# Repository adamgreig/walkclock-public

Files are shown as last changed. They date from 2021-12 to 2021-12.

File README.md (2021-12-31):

# walkclock

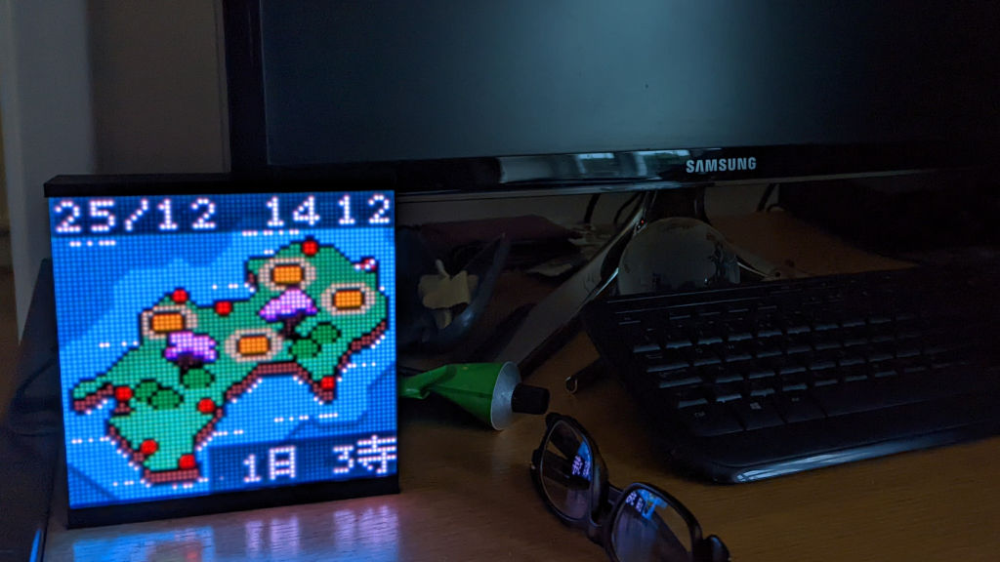
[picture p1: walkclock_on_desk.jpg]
walkclock on a desk


A clock that shows a map with a route that progresses day-by-day.

Display is a 64x64px LED matrix, driven by an STM32H743 on a WeAct dev board.

## Simulator

To run the simulator on a desktop:

```
cd simulator/
cargo run --release
```

The following keyboard buttons are mapped to the buttons on the hardware:

* Q/Backspace/Up: BACK
* W: QR
* E: DISPLAY
* A/Enter/Down: ENTER
* S/Left: LEFT
* D/Right: RIGHT

## Firmware

To program the firmware:

```
cd firmware/
cargo embed --release
```

Use `cargo embed --release rtt` to also attach an RTT session.

## Other Assets

* `mechanical/` contains design files for the 3d-printed holder and laser-cut
  acrylic diffuser
* `artwork/` contains the various maps and images, and a script to extract
  route pixel data from XCF files

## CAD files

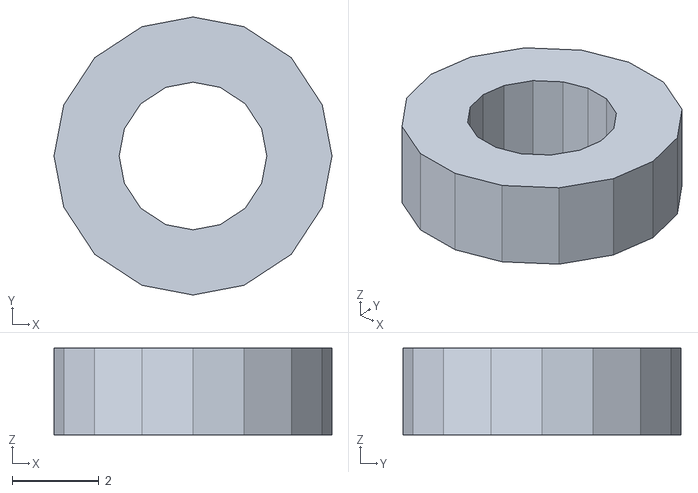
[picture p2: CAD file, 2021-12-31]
mechanical/m3_spacer.stl
6.40 x 6.40 x 2.00

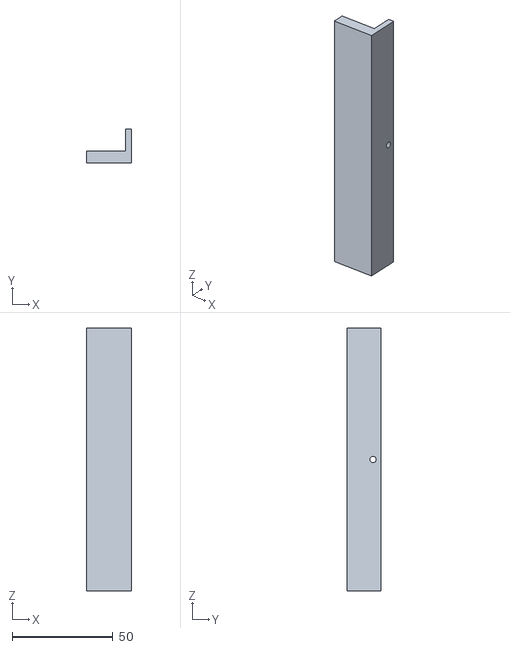
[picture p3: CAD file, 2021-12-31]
mechanical/top_v2.stl
22.2 x 17.0 x 130.5

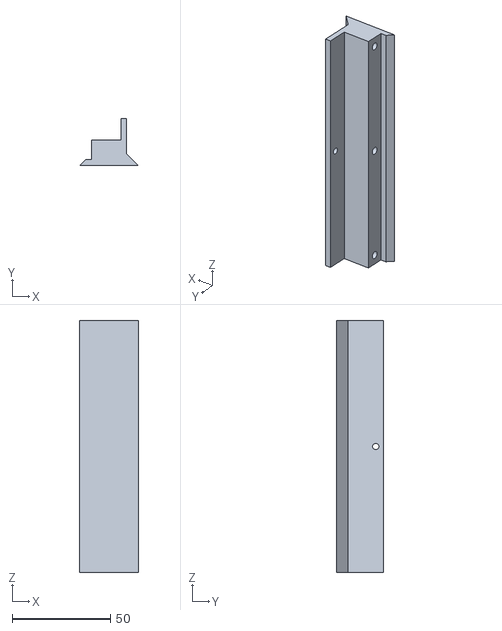
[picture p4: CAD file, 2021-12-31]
mechanical/base.stl
30.0 x 24.0 x 128.0

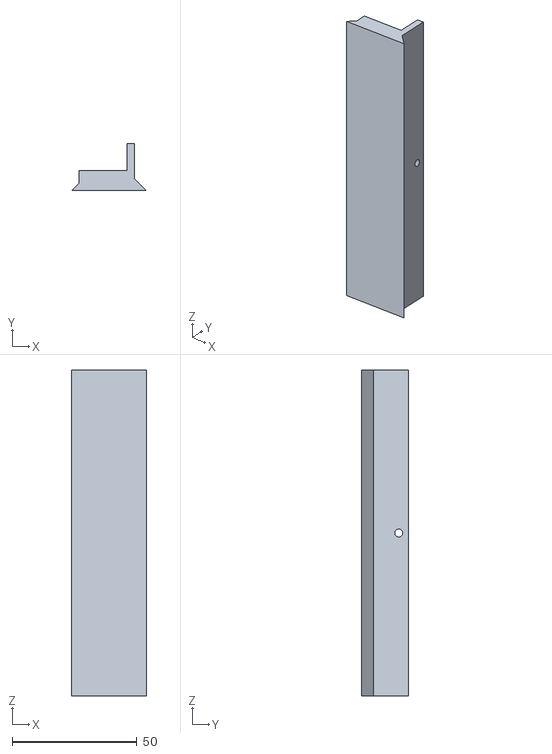
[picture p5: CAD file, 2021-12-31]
mechanical/base_v2.stl
30.0 x 19.0 x 130.5

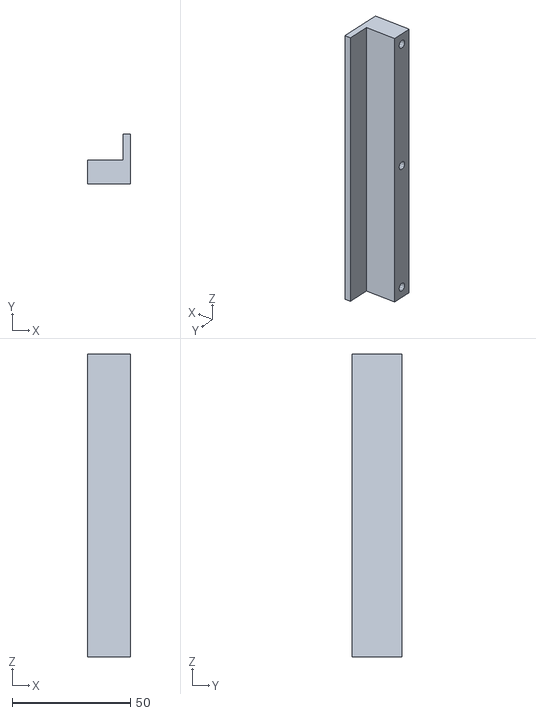
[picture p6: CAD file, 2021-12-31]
mechanical/top.stl
18.0 x 21.0 x 128.0

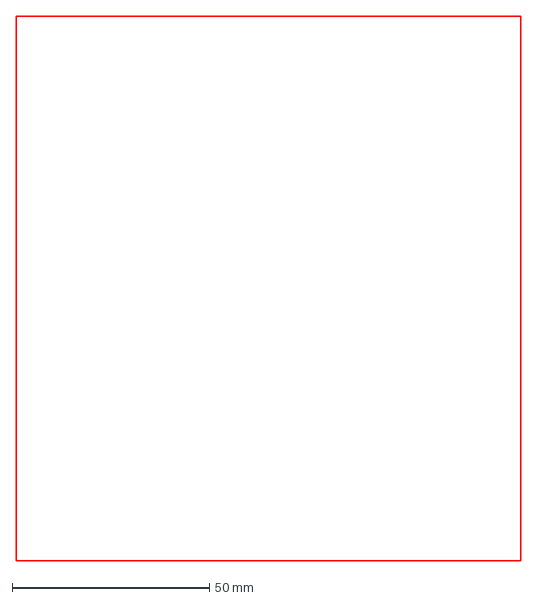
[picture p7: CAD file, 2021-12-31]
mechanical/diffuser_v2.dxf
128.0 x 138.0 mm

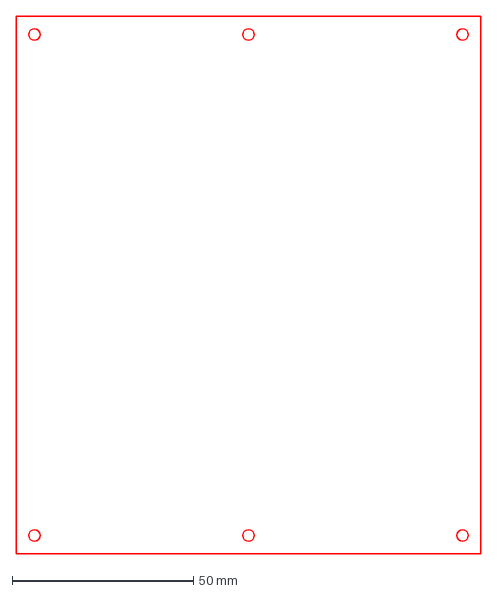
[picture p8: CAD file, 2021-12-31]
mechanical/diffuser.dxf
128.0 x 148.0 mm

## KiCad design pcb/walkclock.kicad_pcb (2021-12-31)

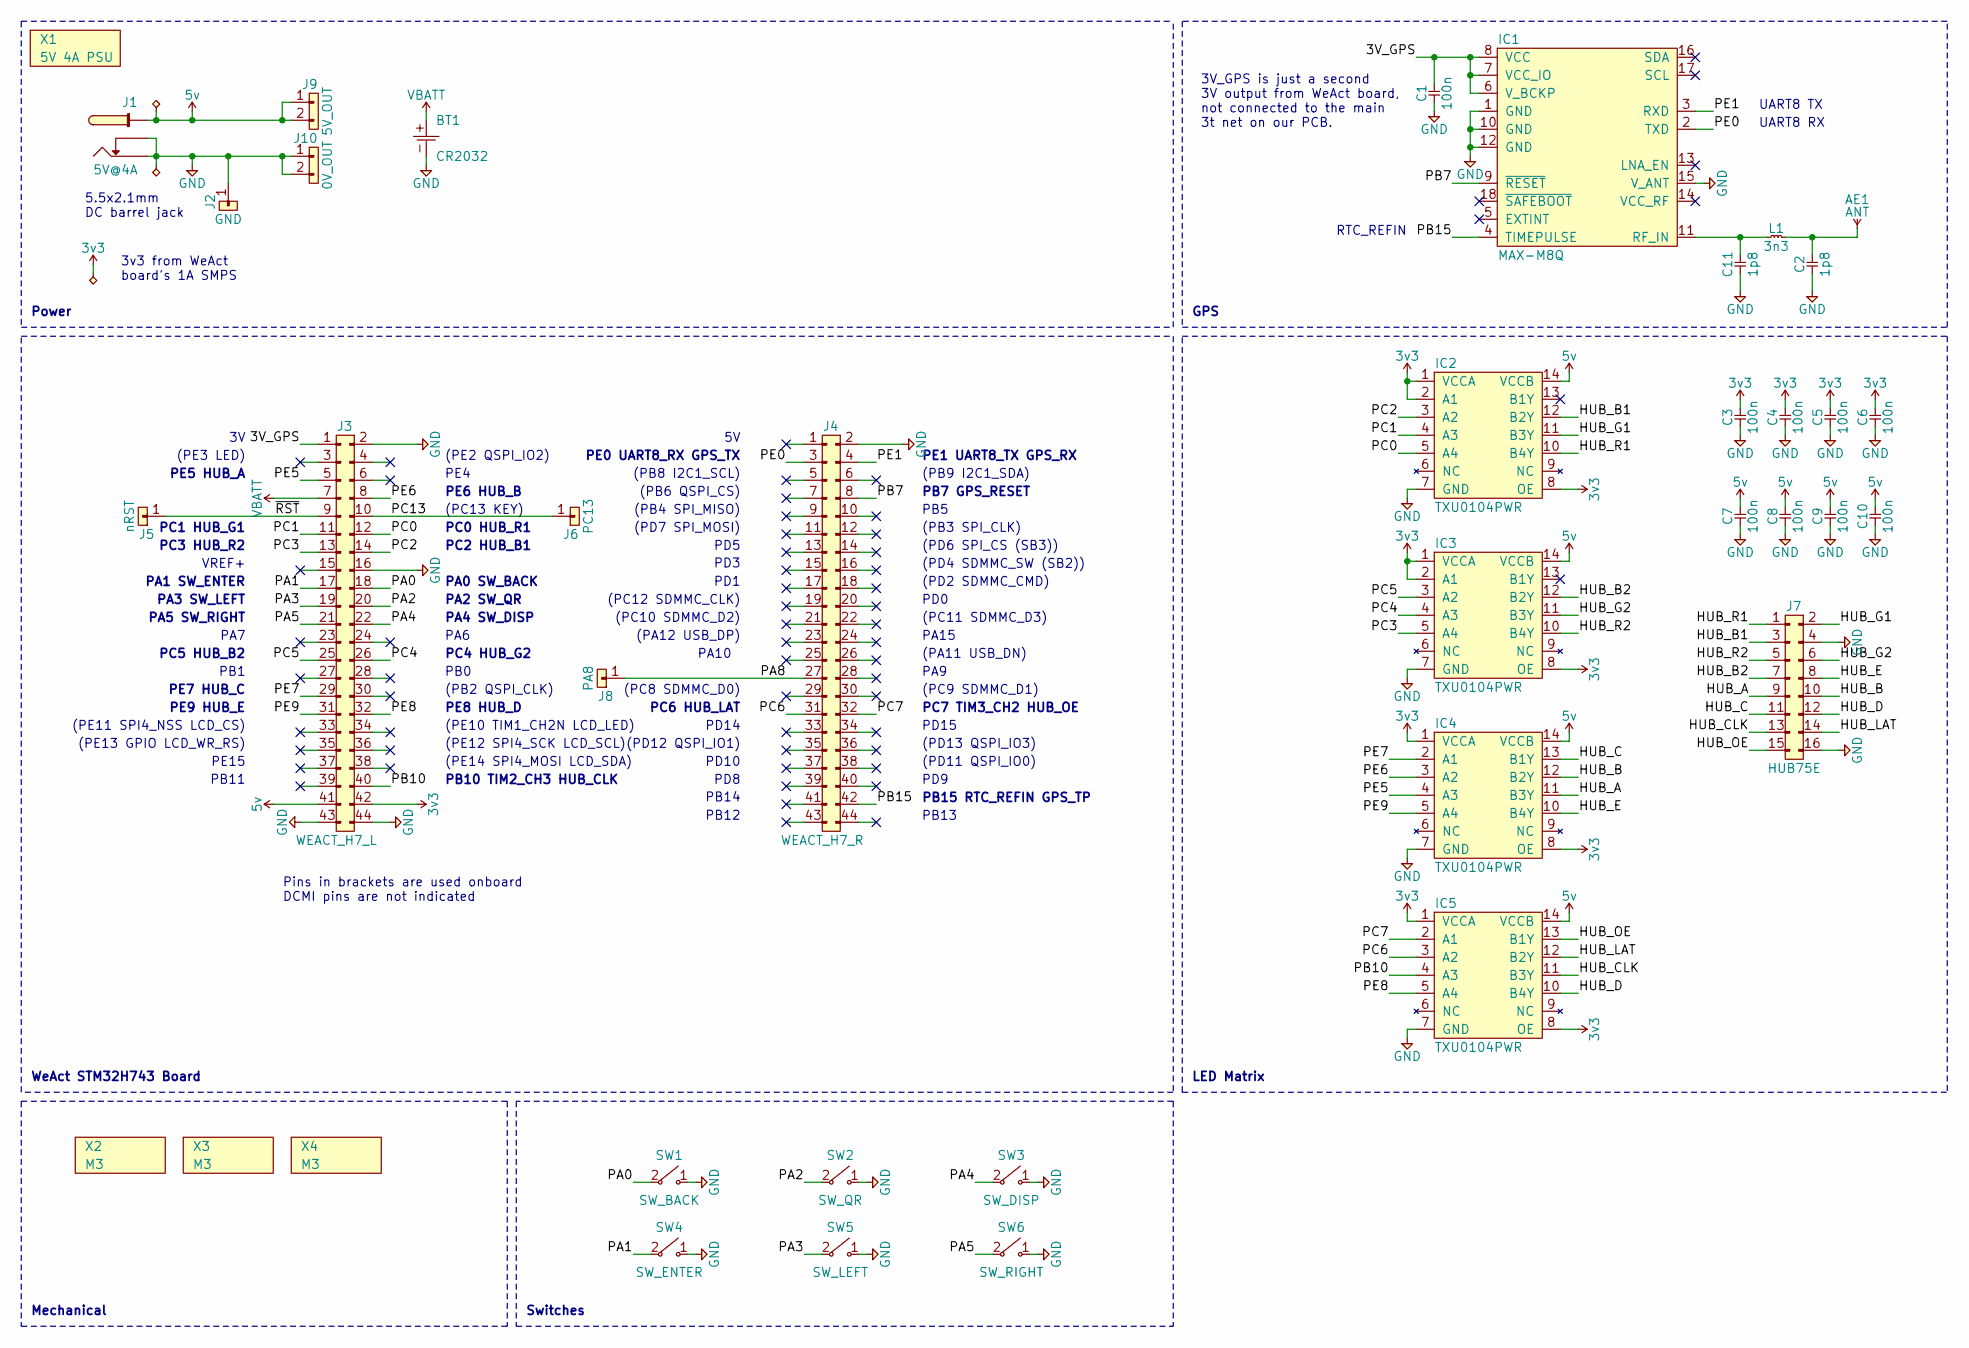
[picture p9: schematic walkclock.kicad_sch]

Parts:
AE1: ANT; NN01-103; Mouser 128-NN01-103
BT1: CR2032; KEYSTONE_103
C1, C3, C4, C5, C6, C7, C8, C9, C10: 100n; 0402; Mouser 963-TMK105BJ104KV8F
C2, C11: 1p8; 0402; Mouser 80-CBR04C189A5GAC
IC1: MAX-M8Q
IC2, IC3, IC4, IC5: TXU0104PWR; TSSOP-14; Mouser 595-TXU0104PWR
J1: 5V@4A; BARRELJACK
J2: GND; SIL-254P-01
J3: WEACT_H7_L; DIL-254P-44; Mouser 200-SSW12201FD
J4: WEACT_H7_R; DIL-254P-44; Mouser 200-SSW12201FD
J5: nRST; SIL-254P-01
J6: PC13; SIL-254P-01
J7: HUB75E; DIL-254P-16; Mouser 200-SSW10801FD
J8: PA8; SIL-254P-01
J9: 5V_OUT; SIL-254P-02
J10: 0V_OUT; SIL-254P-02
L1: 3n3; 0402; Mouser 81-LQW15AN3N3D10D
SW1: SW_BACK; SW_MOM_6X6; Mouser 179-TS046670BK260SMT
SW2: SW_QR; SW_MOM_6X6; Mouser 179-TS046670BK260SMT
SW3: SW_DISP; SW_MOM_6X6; Mouser 179-TS046670BK260SMT
SW4: SW_ENTER; SW_MOM_6X6; Mouser 179-TS046670BK260SMT
SW5: SW_LEFT; SW_MOM_6X6; Mouser 179-TS046670BK260SMT
SW6: SW_RIGHT; SW_MOM_6X6; Mouser 179-TS046670BK260SMT
X1: 5V 4A PSU; Mouser 418-TRE25050U11G02VI
X2, X3, X4: M3; M3_HOLE

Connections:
3v3: C3.2, C4.2, C5.2, C6.2, IC2.1 (VCCA), IC2.2 (A1), IC2.8 (OE), IC3.1 (VCCA), IC3.2 (A1), IC3.8 (OE), IC4.1 (VCCA), IC4.8 (OE), IC5.1 (VCCA), IC5.8 (OE), J3.42
5v: C7.2, C8.2, C9.2, C10.2, IC2.14 (VCCB), IC3.14 (VCCB), IC4.14 (VCCB), IC5.14 (VCCB), J1.1 (TIP), J3.41, J9.1, J9.2
/3V_GPS: C1.2, IC1.6 (V_BCKP), IC1.7 (VCC_IO), IC1.8 (VCC), J3.1
/HUB_A: IC4.11 (B3Y), J7.9
/HUB_B: IC4.12 (B2Y), J7.10
/HUB_B1: IC2.12 (B2Y), J7.3
/HUB_B2: IC3.12 (B2Y), J7.7
/HUB_C: IC4.13 (B1Y), J7.11
/HUB_CLK: IC5.11 (B3Y), J7.13
/HUB_D: IC5.10 (B4Y), J7.12
/HUB_E: IC4.10 (B4Y), J7.8
/HUB_G1: IC2.11 (B3Y), J7.2
/HUB_G2: IC3.11 (B3Y), J7.6
/HUB_LAT: IC5.12 (B2Y), J7.14
/HUB_OE: IC5.13 (B1Y), J7.15
/HUB_R1: IC2.10 (B4Y), J7.1
/HUB_R2: IC3.10 (B4Y), J7.5
/PA0: J3.18, SW1.2 ("~")
/PA1: J3.17, SW4.2 ("~")
/PA2: J3.20, SW2.2 ("~")
/PA3: J3.19, SW5.2 ("~")
/PA4: J3.22, SW3.2 ("~")
/PA5: J3.21, SW6.2 ("~")
/PA8: J4.27, J8.1
/PB7: IC1.9 (~RESET), J4.8
/PB10: IC5.4 (A3), J3.40
/PB15: IC1.4 (TIMEPULSE), J4.42
/PC0: IC2.5 (A4), J3.12
/PC1: IC2.4 (A3), J3.11
/PC2: IC2.3 (A2), J3.14
/PC3: IC3.5 (A4), J3.13
/PC4: IC3.4 (A3), J3.26
/PC5: IC3.3 (A2), J3.25
/PC6: IC5.3 (A2), J4.31
/PC7: IC5.2 (A1), J4.32
/PC13: J3.10, J6.1
/PE0: IC1.2 (TXD), J4.3
/PE1: IC1.3 (RXD), J4.4
/PE5: IC4.4 (A3), J3.5
/PE6: IC4.3 (A2), J3.8
/PE7: IC4.2 (A1), J3.29
/PE8: IC5.5 (A4), J3.32
/PE9: IC4.5 (A4), J3.31
/~RST: J3.9, J5.1
GND: BT1.-, C1.1, C2.1, C3.1, C4.1, C5.1, C6.1, C7.1, C8.1, C9.1, C10.1, C11.1, IC1.1 (GND), IC1.10 (GND), IC1.12 (GND), IC1.15 (V_ANT), IC2.7 (GND), IC3.7 (GND), IC4.7 (GND), IC5.7 (GND), J1.2 (SW), J1.3 (RING), J2.1, J3.2, J3.16, J3.43, J3.44, J4.2, J7.4, J7.16, J10.1, J10.2, SW1.1 ("~"), SW2.1 ("~"), SW3.1 ("~"), SW4.1 ("~"), SW5.1 ("~"), SW6.1 ("~")
unnamed: AE1.1, C2.2, L1.2
unnamed: C11.2, IC1.11 (RF_IN), L1.1
VBATT: BT1.+, J3.7

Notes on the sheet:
(PE11 SPI4_NSS LCD_CS)
(PA11 USB_DN)
PD14
PC1 HUB_G1
5.5x2.1mm DC barrel jack
PD15
Mechanical
PC2 HUB_B1
GPS
(PE13 GPIO LCD_WR_RS)
PE8 HUB_D
UART8 RX
(PB2 QSPI_CLK)
PA7
(PC8 SDMMC_D0)
PA3 SW_LEFT
(PC12 SDMMC_CLK)
(PE10 TIM1_CH2N LCD_LED)
Switches
(PC9 SDMMC_D1)
(PC11 SDMMC_D3)
(PD12 QSPI_IO1)
PC3 HUB_R2
PD9
(PD6 SPI_CS (SB3))
UART8 TX
(PD4 SDMMC_SW (SB2))
(PB6 QSPI_CS)
3v3 from WeAct board's 1A SMPS
(PE12 SPI4_SCK LCD_SCL)
PE0 UART8_RX GPS_TX
PD8
PA15
PB1
(PE2 QSPI_IO2)
PE1 UART8_TX GPS_RX
PE5 HUB_A
PE6 HUB_B
PC4 HUB_G2
PB14

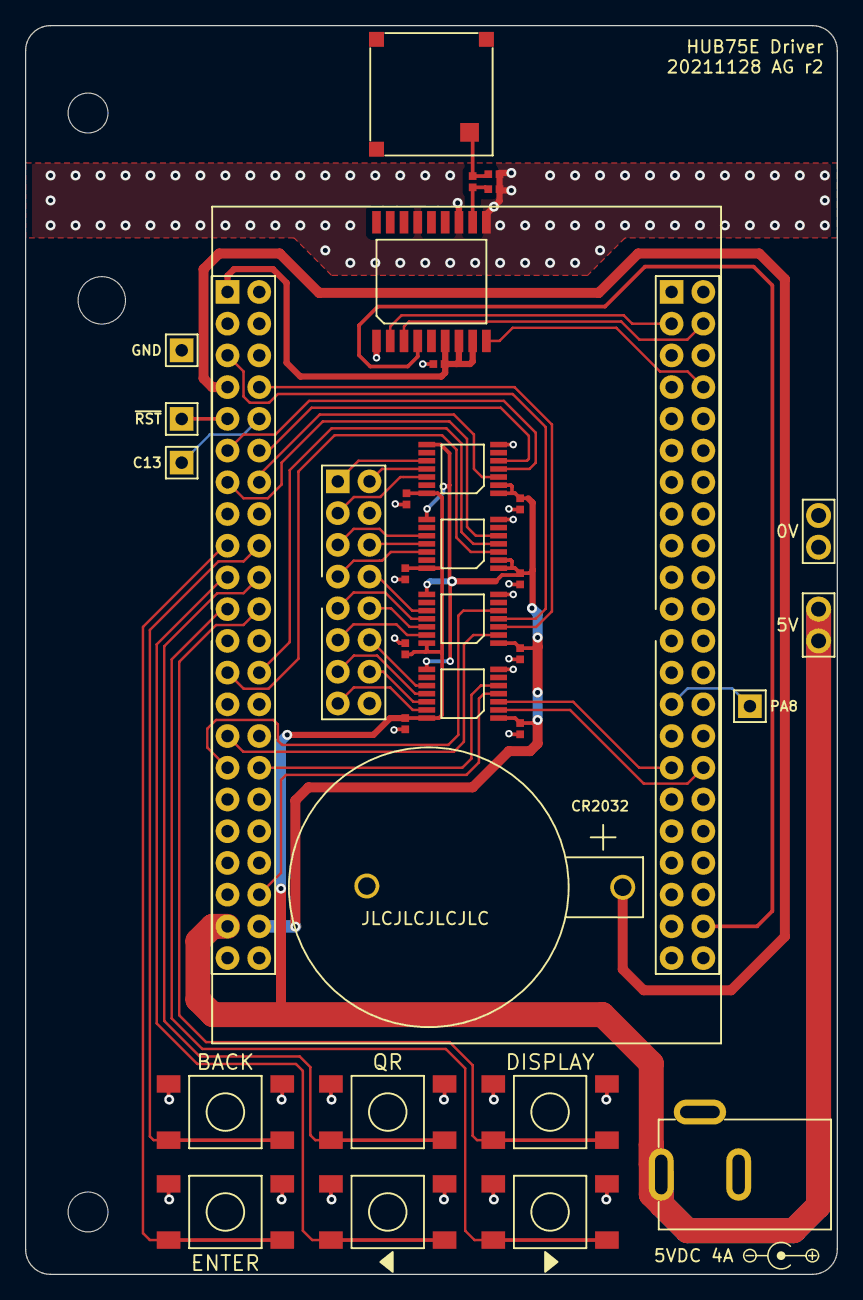
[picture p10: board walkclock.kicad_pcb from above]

Board: 2 copper layers, 65.0 x 100.0 mm, 38 parts (0 on the bottom side), 48 nets.

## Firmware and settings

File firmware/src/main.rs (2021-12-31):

#![no_std]
#![no_main]

use panic_rtt_target as _;
mod dma;
mod dma2d;
mod framebuf;
mod gpio;
mod hub75e;
mod lcd;
mod rcc;
mod rtc;
mod spi;
mod switches;
mod tim;
mod uart;
mod ublox;

mod jpeg;

pub type LineBuf = [u8; 65];

#[rtic::app(device=stm32ral::stm32h7::stm32h743v, dispatchers=[WKUP])]
mod app {
    use crate::{
        dma, dma2d, gpio, jpeg, rcc, rtc, spi, tim, uart,
        lcd::Lcd, ublox::{UBlox, PVTError}, switches::Switches, hub75e::Hub75E,
        LineBuf, framebuf::{FrameBuf, MainFrameBuf, SubFrameBuf},
    };
    use rtt_target::{rtt_init_print, rprintln, rprint};
    use walkclock::Clock;

    /// Double-buffered RGB888 frame buffers for main HUB75E display.
    static mut MFBUFS: [MainFrameBuf; 2] = [FrameBuf([[[0u8; 3]; 64]; 64]); 2];

    /// Output buffers for HUB75E driver, which is read by DMA1 so goes in SRAM1.
    ///
    /// NOTE: Despite being set to 0, SRAM1 is not initialised by the runtime,
    /// so this buffer starts life uninitialised. However, we only ever write
    /// to it from Rust and it's only read by DMA, so we sort of avoid UB.
    #[link_section=".sram1.lbufs"]
    static mut LBUFS: [LineBuf; 2] = [[0u8; 65]; 2];

    /// Single-buffered RGB888 frame buffer for LCD display.
    ///
    /// NOTE: Stored in SRAM2 to enable direct access by DMA,
    ///       while not contending with SRAM1 for the main display.
    #[link_section=".sram2.sfbuf"]
    static mut SFBUF: SubFrameBuf = FrameBuf([[[0u8; 3]; 160]; 80]);

    /// Reception buffer for UART.
    /// NOTE: Stored in SRAM2 to enable direct access by DMA.
    #[link_section=".sram2.uartbuf"]
    static mut UARTBUF: [u8; 100] = [0u8; 100];

    /// TIM15 capture buffer.
    /// Captures 2049 LSE edge timestamps to reconstruct 2048 LSE period measurements,
    /// or half a second worth of LSE ticks at 32768Hz LSE with timer input prescaler 8.
    /// NOTE: Stored in SRAM2 to enable direct access by DMA.
    #[link_section=".sram2.tim15buf"]
    static mut TIM15BUF: [u16; 2049] = [0u16; 2049];

    /// JPEG decode buffer.
    /// Stores decoded MCUs from the most recently processed JPEG.
    /// NOTE: Stored in AXISRAM as it's spacious and can be accessed by CPU and DMA2D.
    #[link_section=".axisram.jpegdbuf"]
    static mut JPEGDBUF: [u32; 3072] = [0u32; 3072];

    /// JPEG framebuffer.
    /// Stores converted JPEG RGB888 pixels ready for copying into active framebuffer.
    /// NOTE: Stored in AXISRAM as it's spacious and can be accessed by DMA2D.
    #[link_section=".axisram.jpegfbuf"]
    static mut JPEGFBUF: MainFrameBuf = FrameBuf([[[0u8; 3]; 64]; 64]);

    #[shared]
    struct Shared {
        hub: Hub75E,
        lcd: Lcd,
        ublox: UBlox,
        cal: rtc::Calibrator,
    }

    #[local]
    struct Local {
        rtc: rtc::RTC,
        tick_tim: tim::Tim,
        tim12: tim::Tim,
        tim15_dma: dma::DMAStream,
        jpeg: jpeg::Jpeg,
        dma2d: dma2d::DMA2D,
        clock: Clock,
        switches: Switches,
    }

    #[init]
    fn init(mut cx: init::Context) -> (Shared, Local, init::Monotonics) {
        rtt_init_print!();
        rprintln!("WalkClock initialising...");

        // Set up clocks, including PWR voltage scaling and flash wait states.
        rprint!("  RCC...      ");
        let clocks = rcc::setup(cx.device.RCC, cx.device.PWR, cx.device.FLASH);
        rprintln!("OK");

        rprint!("  ICACHE...   ");
        cx.core.SCB.enable_icache();
        rprintln!("OK");

        /*
        rprintln!("Testing JPEG decoder...");
        crate::jpeg::test(cx.device.JPEG);
        rprintln!("Done, continuing...");
        */
        rprint!("  JPEG...     ");
        let jpeg = jpeg::Jpeg::new(cx.device.JPEG);
        rprintln!("OK");

        rprint!("  GPIO...     ");
        let pins = gpio::setup(cx.device.GPIOA, cx.device.GPIOB, cx.device.GPIOC,
                               cx.device.GPIOD, cx.device.GPIOE);
        rprintln!("OK");

        rprint!("  Switches... ");
        // Repeat after the first second and then four times per second thereafter.
        let switches = Switches::new(pins.switches, 20, 5);
        rprintln!("OK");

        rprint!("  RTC...      ");
        let rtc = rtc::RTC::new(cx.device.RTC);
        rprintln!("OK");

        rprint!("  TIM...      ");
        // TIM1 is used to generate the LCD backlight PWM at 250kHz and 1/3 duty cycle.
        // TIM2 is used to generate the HUB75E pixel clock at 15MHz.
        // TIM3 is used to generate the HUB75E OE pulses.
        // TIM4 is used to generate the 20Hz display update ticks, prescaled to 10kHz.
        // TIM15 is used to measure LSE, sending timestamps to a buffer via DMA.
        // If need be, TIM2 can be upped to 18.75MHz for a little more brightness.
        let tim1 = tim::Tim::from_tim1(cx.device.TIM1);
        tim1.setup_lcd_pwm(clocks.tim_ck / 250_000);
        tim1.set_lcd_duty((clocks.tim_ck / 250_000) / 3);
        let tim2 = tim::Tim::from_tim2(cx.device.TIM2);
        tim2.setup_hub_clk(clocks.tim_ck / 15_000_000);
        let tim3 = tim::Tim::from_tim3(cx.device.TIM3);
        tim3.setup_hub_oe();
        let tim4 = tim::Tim::from_tim4(cx.device.TIM4);
        tim4.setup_tick(clocks.tim_ck / 10_000, 500);
        let tim12 = tim::Tim::from_tim12(cx.device.TIM12);
        tim12.setup_psc50_ti2();
        let tim15 = tim::Tim::from_tim15(cx.device.TIM15);
        tim15.setup_tim15_lse();
        rprintln!("OK");

        rprint!("  SPI...      ");
        let spi4 = spi::Spi::new(cx.device.SPI4);
        spi4.setup_lcd(&clocks);
        rprintln!("OK");

        rprint!("  UART...     ");
        let uart8 = uart::Uart::new(cx.device.UART8);
        uart8.setup_ublox(&clocks);
        rprintln!("OK");

        rprint!("  DMA...      ");
        // ID 20  TIM2_CH3  => DMAMUX 0  => DMA1 stream 0
        // ID 81  UART8_RX  => DMAMUX 8  => DMA2 stream 0
        // ID 84  SPI4_TX   => DMAMUX 9  => DMA2 stream 1
        // ID 105 TIM15_CH1 => DMAMUX 10 => DMA2 stream 2
        let dmamux = dma::DMAMux1::new(cx.device.DMAMUX1);
        dmamux.set(0, 20);
        dmamux.set(8, 81);
        dmamux.set(9, 84);
        dmamux.set(10, 105);
        let dma1 = dma::DMA::new(cx.device.DMA1);
        dma1.s0.setup_tx(pins.hub.odr());
        let dma2 = dma::DMA::new(cx.device.DMA2);
        dma2.s0.setup_rx(uart8.rdr());
        dma2.s0.set_trbuff();
        dma2.s1.setup_tx(spi4.txdr());
        dma2.s2.setup_u16_rx(tim15.ccr1());
        let dma2d = dma2d::DMA2D::new(cx.device.DMA2D);
        rprintln!("OK");

        rprint!("  uBlox...    ");
        // NOTE(unsafe): DMA writes to this buffer which must live in SRAM2 and be static,
        // NOTE(unsafe): but we are careful to only read when DMA is not active.
        let buf = unsafe { &mut UARTBUF };
        let ublox = UBlox::new(uart8, pins.gps_reset, dma2.s0, buf);
        ublox.setup();
        rprintln!("OK");

        rprint!("  Clock...    ");
        let mut clock = Clock::new();
        let mut settings = [0u32; 32];
        rtc.read_backup(&mut settings[..]);
        clock.deserialise(&settings[..]);
        rprintln!("OK");

        rprint!("  LCD...      ");
        let lcd = Lcd::new(spi4, pins.lcd_wr_rs, dma2.s1);
        lcd.start();
        rprintln!("OK");

        rprint!("  HUB...      ");
        // NOTE(unsafe): We manage frame buffer swapping manually, with the shared reference
        // NOTE(unsafe): created here being read by the HUB75E driver, and later swapped
        // NOTE(unsafe): out for a freshly drawn buffer.
        let mfbuf = unsafe { &MFBUFS[1] };
        // NOTE(unsafe): The line buffers are only accessed through this single mutable reference.
        let lbufs = unsafe { &mut LBUFS };
        // We use bcm_base=18, giving 18/150MHz = 120ns as the smallest OE pulse.
        let mut hub = Hub75E::new(pins.hub, tim2, tim3, dma1.s0, mfbuf, lbufs, 18);
        hub.start();
        rprintln!("OK");

        rprintln!("Initialisation complete.");

        // Start capturing LSE measurements.
        // NOTE(unsafe): Written to by DMA, then read in DMA interrupt while DMA is stopped.
        dma2.s2.start_u16_rx(unsafe { &mut TIM15BUF[..]});

        // Start timer for 20Hz main render loop ticks.
        tim4.start();

        (
            Shared {
                hub,
                lcd,
                ublox,
                cal: rtc::Calibrator::new(),
            },

            Local {
                rtc,
                tick_tim: tim4,
                tim12,
                tim15_dma: dma2.s2,
                jpeg,
                dma2d,
                clock,
                switches,
            },

            init::Monotonics {}
        )
    }

    /// Empty idle handler prevents low-power sleep mode
    /// between interrupts, which takes long enough to resume
    /// from that it can interfere with HUB75E timing.
    #[idle]
    fn idle(_: idle::Context) -> ! {
        loop {}
    }

    /// HUB75 DMA write completion interrupt.
    #[task(binds=DMA_STR0, priority=5, shared=[hub])]
    fn dma_hub75(mut cx: dma_hub75::Context) {
        cx.shared.hub.lock(|hub| hub.dma_isr());
    }

    /// HUB75 OE pulse completion interrupt.
    #[task(binds=TIM3, priority=5, shared=[hub])]
    fn tim_oe(mut cx: tim_oe::Context) {
        cx.shared.hub.lock(|hub| hub.tim_oe_isr());
    }

    /// LCD DMA write completion interrupt.
    #[task(binds=DMA2_STR1, priority=4, shared=[lcd])]
    fn dma_lcd(mut cx: dma_lcd::Context) {
        cx.shared.lcd.lock(|lcd| lcd.dma_isr());
    }

    /// UART DMA interrupt.
    #[task(binds=DMA2_STR0, priority=3, shared=[ublox])]
    fn dma_ublox(mut cx: dma_ublox::Context) {
        cx.shared.ublox.lock(|ublox| ublox.dma_isr());
    }

    /// UART IDLE interrupt.
    #[task(binds=UART8, priority=3, shared=[ublox])]
    fn uart_ublox(mut cx: uart_ublox::Context) {
        cx.shared.ublox.lock(|ublox| ublox.uart_isr());
    }

    /// TIM12 interrupt.
    /// Configured for CC2 capture, which measures the period of the GPS 50Hz timepulse.
    /// Sums the difference of the last 50 CC2 captures to effectively measure HSE frequency.
    #[task(
        binds=TIM8_BRK_TIM12,
        local=[tim12, n: u32 = 0, s: u32 = 0, p: u16 = 0],
        shared=[cal],
        priority=1
    )]
    fn tim12(mut cx: tim12::Context) {
        cx.local.tim12.clear_uif();
        let cc2 = cx.local.tim12.cc2() as u16;
        *cx.local.n += 1;
        *cx.local.s += (cc2 - *cx.local.p) as u32;
        *cx.local.p = cc2;
        if *cx.local.n == 50 {
            cx.shared.cal.lock(|cal| cal.gps_reading(*cx.local.s));
            *cx.local.n = 0;
            *cx.local.s = 0;
        }
    }

    /// TIM15 DMA interrupt.
    /// Computes the number of APB ticks for 16384 ticks of LSE.
    #[task(binds=DMA2_STR2, priority=1, local=[tim15_dma], shared=[cal])]
    fn tim15_dma(mut cx: tim15_dma::Context) {
        // Compute APB ticks between first and last LSE tick by summing the difference
        // between each timestamped tick.
        // NOTE(unsafe): DMA is disabled when this interrupt is entered until we restart it.
        let buf = unsafe { &TIM15BUF[..] };
        let sum: u32 = buf.windows(2).map(|w| (w[1] - w[0]) as u32).sum();
        cx.shared.cal.lock(|cal| cal.lse_reading(sum));

        // Restart DMA processing.
        // NOTE(unsafe): Written to by DMA, then read in DMA interrupt while DMA is stopped.
        cx.local.tim15_dma.start_u16_rx(unsafe { &mut TIM15BUF[..]});
    }

    /// Main loop 20Hz timer tick.
    ///
    /// Processes new GPS messages, handles updates from the clock application,
    /// then renders both displays.
    #[task(
        binds=TIM4,
        priority=2,
        local=[
            rtc, clock, tick_tim, switches, jpeg, dma2d,
            fbuf_idx: usize = 0, nolock_time: u32 = 0, prev_jpeg: u32 = 0,
        ],
        shared=[hub, lcd, ublox, cal],
    )]
    fn tim_tick(mut cx: tim_tick::Context) {
        cx.local.tick_tim.clear_uif();

        // Process button inputs.
        cx.local.switches.update();
        if cx.local.switches.back() {
            cx.local.clock.key_back();
        }
        if cx.local.switches.qr() {
            cx.local.clock.key_qr();
        }
        if cx.local.switches.display() {
            cx.local.clock.key_display();
        }
        if cx.local.switches.enter() {
            cx.local.clock.key_enter();
        }
        if cx.local.switches.left() {
            cx.local.clock.key_left();
        }
        if cx.local.switches.right() {
            cx.local.clock.key_right();
        }

        if cx.local.clock.use_gps_time() {
            // Process any newly received GNSS times.
            match cx.shared.ublox.lock(|ublox| ublox.pvt()) {
                Ok(pvt) => {
                    if pvt.fix {
                        *cx.local.nolock_time = 0;
                        if pvt.valid_date && pvt.valid_time && pvt.fully_resolved {
                            cx.local.clock.set_gps_lock_valid(pvt.num_sv);
                            cx.local.rtc.new_pvt(&pvt);
                        } else {
                            cx.local.clock.set_gps_lock_invalid(pvt.num_sv);
                        }
                    } else {
                        *cx.local.nolock_time += 1;
                        cx.local.clock.set_gps_no_lock(*cx.local.nolock_time);
                    }
                },

                // Allow 30 NoPVTs in a row before declaring an error due to missing data.
                // At 20Hz render loop, we only expect to see one PVT every 20 cycles anyway.
                Err(PVTError::NoPVT(n)) => if n > 30 {
                    cx.local.clock.set_gps_error();
                    if n % 32 == 0 {
                        // Rate-limit timeout error printing just to avoid spamming rtt console.
                        rprintln!("GPS timeout: {:?}", n);
                    }
                },

                // Any other error is an immediate failure we can report.
                Err(e) => {
                    cx.local.clock.set_gps_error();
                    rprintln!("GPS error: {:?}", e);
                }
            }
        } else {
            // Indicate that GPS is not being used on the status screen.
            cx.local.clock.set_gps_unused();

            // Check if the user has changed the clock time via the menu, and update RTC if so.
            if cx.local.clock.time_changed() {
                let (year, month, day, hour, minute, second) = cx.local.clock.menu_time();
                let year = (year - 2000) as u8;
                let dt = rtc::DateTime { year, month, day, hour, minute, second };
                cx.local.rtc.set(&dt);
            }
        }

        // Get the current brightness from the application and convert
        // to number of BCM phases to skip.
        let bcm_skip = 10 - cx.local.clock.brightness();

        // Update the application with the latest date and time from the RTC.
        let time = cx.local.rtc.read();
        cx.local.clock.set_time(
            time.year as u16 + 2000, time.month, time.day, time.hour, time.minute, time.second);

        // At the middle of each hour, process potential RTC calibration.
        if time.minute == 30 {
            if time.second == 0 {
                // At 0 seconds, clear any old saved data and enable capturing new data.
                cx.shared.cal.lock(|cal| cal.clear());
                gpio::pb15_tim();
            } else if time.second == 6 {
                // At 6 seconds, apply a calibration if valid, and set GPIO back to RTC ref.
                if let Some((calp, calm)) = cx.shared.cal.lock(|cal| cal.cal()) {
                    rprintln!("Setting RTC calibration to CALP={} CALM={}", calp, calm);
                    cx.local.rtc.set_calibration(calp, calm);
                }
                gpio::pb15_rtc();
            }
        }

        // If the application state has changed, save it to backup registers.
        if cx.local.clock.needs_saving() {
            let mut settings = [0u32; 32];
            cx.local.clock.serialise(&mut settings[..]);
            cx.local.rtc.write_backup(&settings[..]);
        }

        // NOTE(unsafe): Get the frame buffer not currently used by the HUB75E driver,
        // NOTE(unsafe): we'll write to it and then swap it into the driver.
        let mfbuf = unsafe { &mut MFBUFS[*cx.local.fbuf_idx] };

        // Check if we need to render a JPEG first.
        if let Some(jpeg) = cx.local.clock.prerender_jpeg() {
            // NOTE(unsafe): JPEGFBUF may be written to by DMA2D during this lifetime,
            // NOTE(unsafe): and then is copied into MFBUF once DMA2D is complete.
            let jpegfbuf = unsafe { &mut JPEGFBUF };

            if jpeg.as_ptr() as u32 != *cx.local.prev_jpeg {
                // NOTE(unsafe): JPEGDBUF will only be written to by the JPEG peripheral
                // NOTE(unsafe): and then read by DMA2D, all during the lifetime of this ref.
                let jpegdbuf = unsafe { &mut JPEGDBUF };

                // Decode provided JPEG.
                if let Err(e) = cx.local.jpeg.decode(jpeg, jpegdbuf) {
                    rprintln!("Error decoding JPEG: {:?}", e);
                    mfbuf.clear_black();
                }

                // Convert (possibly already decoded) JPEG data into RGB888 in the framebuffer.
                if let Err(e) = cx.local.dma2d.convert_jpeg(jpegdbuf, jpegfbuf) {
                    rprintln!("Error converting JPEG: {:?}", e);
                    mfbuf.clear_black();
                }

                // Remember the last JPEG we decoded to save reprocessing it next time.
                *cx.local.prev_jpeg = jpeg.as_ptr() as u32;
            }

            // Copy the processed JPEG image into the main framebuffer in DTCM.
            mfbuf.0.copy_from_slice(&jpegfbuf.0);

        } else {

            // If not drawing a JPEG, clear the screen to black instead.
            mfbuf.clear_black();
        }

        // Render the main display.
        cx.local.clock.render_main(mfbuf);
        cx.shared.hub.lock(|hub| {
            hub.set_bcm_skip(bcm_skip);
            hub.set_fbuf(mfbuf);
        });

        // Use next framebuffer next time.
        *cx.local.fbuf_idx ^= 1;

        // NOTE(unsafe): While we cannot verify it statically, our realtime deadline for
        // NOTE(unsafe): memory safety is that the DMA transfer of the previous render
        // NOTE(unsafe): completes before this render operation. At 9.375MHz SPI clock,
        // NOTE(unsafe): it takes 32.768ms to write one frame, and we render every 50ms.
        let sfbuf = unsafe { &mut SFBUF };

        // Render the sub display and trigger the DMA write to the SPI LCD.
        sfbuf.clear_black();
        cx.local.clock.render_sub(sfbuf);
        cx.shared.lcd.lock(|lcd| lcd.write_fbuf(sfbuf));
    }
}

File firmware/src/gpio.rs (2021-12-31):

#![allow(dead_code)]

use stm32ral::{gpio, read_reg, write_reg, modify_reg};

type Gpio = gpio::Instance;

/// [`InputPin`] for each switch.
#[allow(clippy::manual_non_exhaustive)]
pub struct Switches {
    pub back: InputPin,
    pub qr: InputPin,
    pub display: InputPin,
    pub enter: InputPin,
    pub left: InputPin,
    pub right: InputPin,
    _private: (),
}

/// HUB75E interface.
///
/// Provides methods for efficiently setting the address lines, and accessing the ODR register
/// address for the data, clock, and latch lines.
pub struct Hub {
    addr_bsrr: u32,
    addr_offset: usize,
    data_odr: u32,
}

impl Hub {
    /// Set the address lines A-E to the provided 5-bit value.
    pub fn set_addr(&self, addr: u8) {
        // NOTE(unsafe): Write-only access to atomic bit-set register.
        // NOTE(unsafe): No other code accesses this register.
        unsafe {
            core::ptr::write_volatile(
                self.addr_bsrr as *mut u32,
                // Reset all address bits.
                (0b11111 << (self.addr_offset + 16)) |
                // Set relevant bits, taking priority over reset.
                ((addr as u32) << self.addr_offset)
            );
        }
    }

    /// Get the address of the data register to DMA into for
    /// R1, G1, B1, R2, G2, B2, LAT, OE signals.
    pub fn odr(&self) -> u32 {
        self.data_odr
    }
}

/// Pins container.
///
/// Contains the results of setting up the GPIOs,
/// including access to switches, the HUB75E interface, and the GPIOs.
#[allow(clippy::manual_non_exhaustive)]
pub struct Pins {
    pub switches: Switches,
    pub hub: Hub,
    pub gps_reset: OutputPin,
    pub led: OutputPin,
    pub lcd_wr_rs: OutputPin,
    _private: (),
}

pub fn setup(gpioa: Gpio, gpiob: Gpio, gpioc: Gpio, _gpiod: Gpio, gpioe: Gpio) -> Pins {
    // GPIOA
    // PA0: Input pulled up, SW_BACK
    // PA1: Input pulled up, SW_ENTER
    // PA2: Input pulled up, SW_QR
    // PA3: Input pulled up, SW_LEFT
    // PA4: Input pulled up, SW_DISP
    // PA5: Input pulled up, SW_RIGHT
    // PA6-7: Unused
    // PA8: AF0, MCO1 for LSE calibration
    // PA9-12: Unused
    // PA13: AF0 SWDIO pulled up
    // PA14: AF0 SWCLK pulled down
    // PA15: Unused.
    write_reg!(gpio, gpioa, ODR, 0);
    write_reg!(gpio, gpioa, MODER, MODER0: Input, MODER1: Input, MODER2: Input,
                                   MODER3: Input, MODER4: Input, MODER5: Input,
                                   MODER8: Alternate, MODER13: Alternate, MODER14: Alternate);
    write_reg!(gpio, gpioa, PUPDR, PUPDR0: PullUp, PUPDR1: PullUp, PUPDR2: PullUp,
                                   PUPDR3: PullUp, PUPDR4: PullUp, PUPDR5: PullUp,
                                   PUPDR13: PullUp, PUPDR14: PullDown);
    write_reg!(gpio, gpioa, AFRH, AFR8: 0, AFR13: 0, AFR14: 0);

    // GPIOB
    // PB0-PB6: Unused
    // PB7: Output, GPS_RESET
    // PB8-9: Unused
    // PB10: AF1, TIM2_CH3, HUB_CLK
    // PB11-14: Unused
    // PB15: AF0, RTC_REFIN
    write_reg!(gpio, gpiob, ODR, 0);
    write_reg!(gpio, gpiob, MODER, MODER7: Output, MODER10: Alternate, MODER15: Alternate);
    write_reg!(gpio, gpiob, OSPEEDR, OSPEEDR10: MediumSpeed);
    write_reg!(gpio, gpiob, AFRH, AFR10: 1, AFR15: 0);

    // GPIOC
    // PC0: Output, HUB_R1
    // PC1: Output, HUB_G1
    // PC2: Output, HUB_B1
    // PC3: Output, HUB_R2
    // PC4: Output, HUB_G2
    // PC5: Output, HUB_B2
    // PC6: Output, HUB_LAT
    // PC7: AF2, TIM3_CH2, HUB_OE
    // PC8-PC12: Unused
    // PC13: Input, KEY / RTC_CALIB
    // PC14-PC15: Unused
    // HUB pins need to be medium speed <=60MHz.
    write_reg!(gpio, gpioc, ODR, 0);
    write_reg!(gpio, gpioc, MODER, MODER0: Output, MODER1: Output, MODER2: Output, MODER3: Output,
                                   MODER4: Output, MODER5: Output, MODER6: Output,
                                   MODER7: Alternate, MODER13: Input);
    write_reg!(gpio, gpioc, OSPEEDR, OSPEEDR0: MediumSpeed, OSPEEDR1: MediumSpeed,
                                     OSPEEDR2: MediumSpeed, OSPEEDR3: MediumSpeed,
                                     OSPEEDR4: MediumSpeed, OSPEEDR5: MediumSpeed,
                                     OSPEEDR6: MediumSpeed, OSPEEDR7: MediumSpeed);
    write_reg!(gpio, gpioc, AFRL, AFR7: 2);

    // GPIOD
    // PD0-15: Unused

    // GPIOE
    // PE0: AF8, UART8_RX, GPS_TX
    // PE1: AF8, UART8_TX, GPS_RX
    // PE2: Unused
    // PE3: Output, LED
    // PE4: Unused
    // PE5: Output, HUB_A
    // PE6: Output, HUB_B
    // PE7: Output, HUB_C
    // PE8: Output, HUB_D
    // PE9: Output, HUB_E
    // PE10: AF1, TIM1_CH2N, LCD_LED
    // PE11: AF5, SPI4_NSS, LCD_CS
    // PE12: AF5, SPI4_SCK, LCD_SCL
    // PE13: Output, LCD_WR_RS
    // PE14: AF5, SPI4_MOSI, LCD_SDA
    // PE15: Unused
    // HUB pins and SPI pins need to be medium speed <=60MHz.
    write_reg!(gpio, gpioe, ODR, 0);
    write_reg!(gpio, gpioe, MODER, MODER0: Alternate, MODER1: Alternate, MODER3: Output,
                                   MODER5: Output, MODER6: Output, MODER7: Output, MODER8: Output,
                                   MODER9: Output, MODER10: Alternate, MODER11: Alternate,
                                   MODER12: Alternate, MODER13: Output, MODER14: Alternate);
    write_reg!(gpio, gpioe, OSPEEDR, OSPEEDR0: LowSpeed, OSPEEDR1: LowSpeed, OSPEEDR3: LowSpeed,
                                     OSPEEDR5: MediumSpeed, OSPEEDR6: MediumSpeed,
                                     OSPEEDR7: MediumSpeed, OSPEEDR8: MediumSpeed,
                                     OSPEEDR9: MediumSpeed, OSPEEDR10: LowSpeed,
                                     OSPEEDR11: MediumSpeed, OSPEEDR12: MediumSpeed,
                                     OSPEEDR13: LowSpeed, OSPEEDR14: MediumSpeed);
    write_reg!(gpio, gpioe, PUPDR, PUPDR0: PullUp);
    write_reg!(gpio, gpioe, AFRL, AFR0: 8, AFR1: 8);
    write_reg!(gpio, gpioe, AFRH, AFR10: 1, AFR11: 5, AFR12: 5, AFR14: 5);

    let switches = Switches {
        back:       InputPin::new(&gpioa, 0),
        qr:         InputPin::new(&gpioa, 2),
        display:    InputPin::new(&gpioa, 4),
        enter:      InputPin::new(&gpioa, 1),
        left:       InputPin::new(&gpioa, 3),
        right:      InputPin::new(&gpioa, 5),
        _private: (),
    };

    let hub = Hub {
        addr_bsrr: &gpioe.BSRR as *const _ as u32,
        addr_offset: 5,
        data_odr: &gpioc.ODR as *const _ as u32,
    };

    Pins {
        switches,
        hub,
        gps_reset:  OutputPin::new(&gpiob, 7),
        led:        OutputPin::new(&gpioe, 3),
        lcd_wr_rs:  OutputPin::new(&gpioe, 13),
        _private: (),
    }
}

/// Pin for runtime control of outputs.
pub struct OutputPin {
    bsrr: u32,
    pin: u32,
}
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
